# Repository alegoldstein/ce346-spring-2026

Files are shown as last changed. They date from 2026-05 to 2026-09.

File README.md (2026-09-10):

# Electronic Game Table
# ce346-spring-2026

Firmware and PCB design for COMP_ENG 346: Microcontroller System Design.

For this project my group created an electronic table that added animations and score tracking to the common college games of beer pong and beer die.

To do so, we CNC'd a wooden table with channels to pour epoxy and placed ~800 WS2812B LEDs. Each half of the table had its own PCB (which are identical) which was responsible for monitoring the game state and controlling the LEDs accordingly using the FastLED library. Lastly, the power for this project was a large challenge because of the high current draw that WS2812B LEDs are capable of. To avoid overheating, we never had LEDs on at full brightness and avoided the color white as much as possible. The power source we used was capable of supplying 60A at 5V so monitoring shorts was also a high priority. We used bus bars that were suited for handling 60A and separated power and ground with large margins to avoid any accidental shorts. To ensure a uniform brightness level we added power injections to the LED strips with carefuly planned channels cut around in the available space left around the epoxy. 

<table align="center">
  <tr>
    <td align="center">
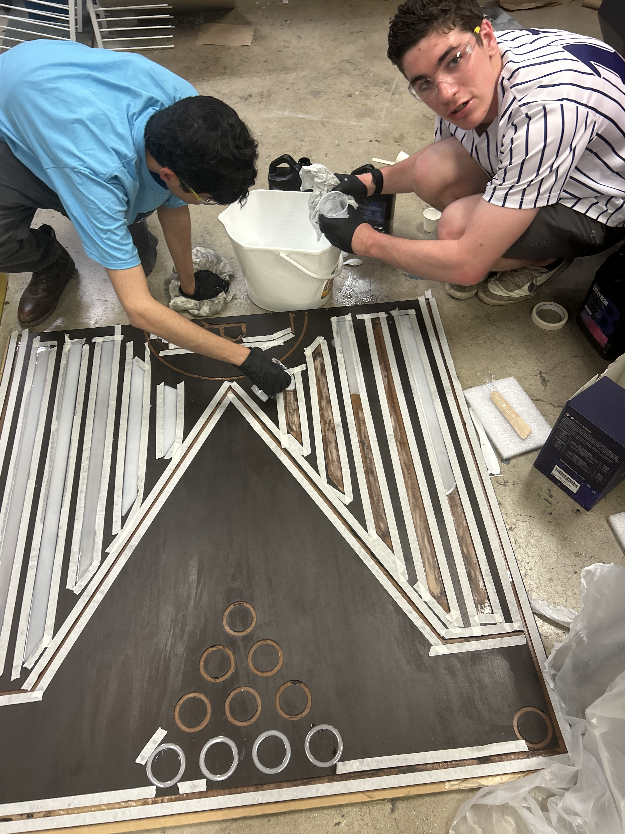
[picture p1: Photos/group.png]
      <br>
      <em>The three of us pouring epoxy</em>
    </td>
    <td align="center">
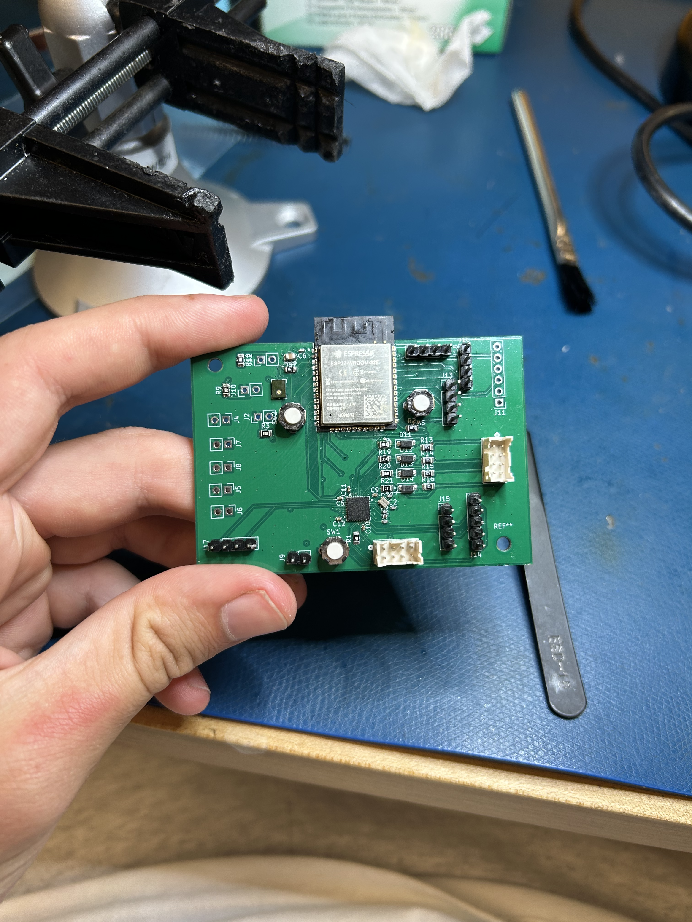
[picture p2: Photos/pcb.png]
      <br>
      <em>Fully assembled PCB</em>
    </td>
  </tr>
</table>

<table align="center">
  <tr>
    <td align="center">
      <br>
      <em>Inside of table while routing power and LEDs</em>
    </td>
    <td align="center">
      <br>
      <em>Setting up for demo, LED ring on where cup is placed</em>
    </td>
  </tr>
</table>

I hand wrote the game state code in C for an NRF52833 chip (found in NRF->software->apps->rave_rack) that used a 16 bit variable where bits 0-11 each represented 1 of the 12 cups on a half of a board (10 for pong and 2 for die). The NRF chip was also responsible for cycling through an 16 channel analog multiplexer used to check the values of IR sensors placed beneath each cup to determine whether they had been picked up or not. This information can be used to update the game state and infer the score (more cups missing means other teams score goes up). The NRF chip then communicates the game state to an ESP32 which was responsible for controlling the LEDs.

I also wrote C++ code for the ESP32 to animate the LEDs in response to game state changes. For example, during initialization the LEDs would snake around the border to indicate it was turned on and ready. If a cup was lifted (meaning someone scored) a celebration animation would occur. The FastLED library made this simpler since all that was needed was a buffer with each color and brightness we wanted each LED.

The reasoning for having 2 separate MCUs is due to the class being based on the NRF52833 chip, but our group running out of pins since we had a larger scope than expected for a 4 week project. 

https://github.com/user-attachments/assets/d65dbca0-1492-469c-94e2-22f77370f840

One half of the table featuring LED animations with epoxy cover on top

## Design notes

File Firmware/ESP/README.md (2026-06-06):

ESP controls LEDs under the table and the scoreboard

nrf52833 sends the game state over spi and the ESP responds accordingly

the ESP has the game mode switch button which it will communicate if pressed to the nrf

the two halfs of the table communicate via the ESP of each board being connected with UART

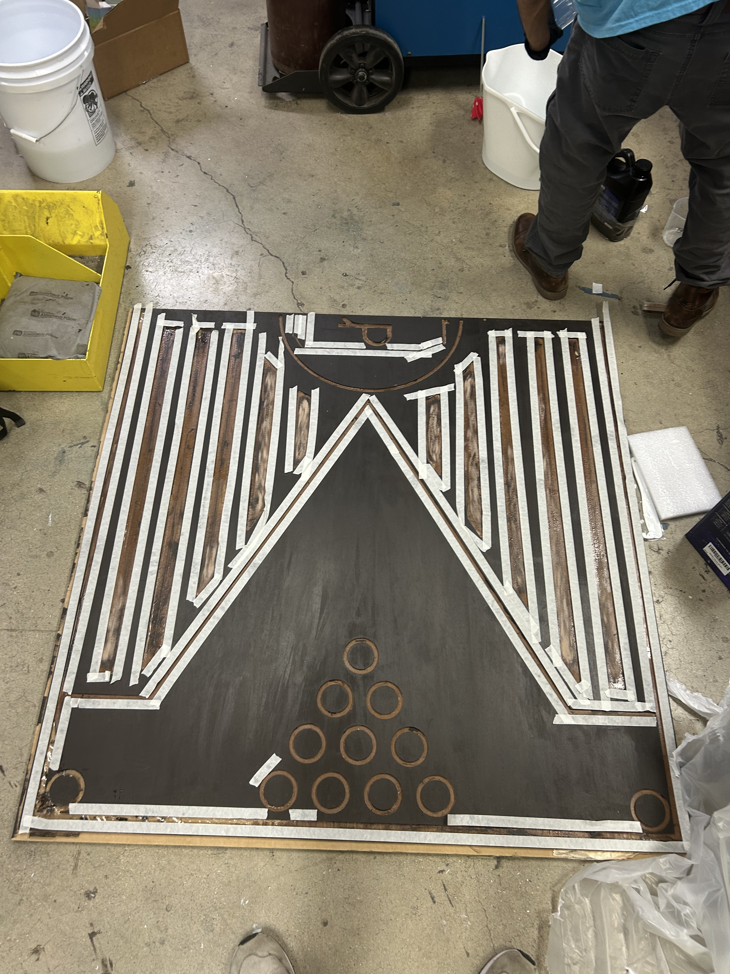
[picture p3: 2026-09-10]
Photos/Epoxy.png

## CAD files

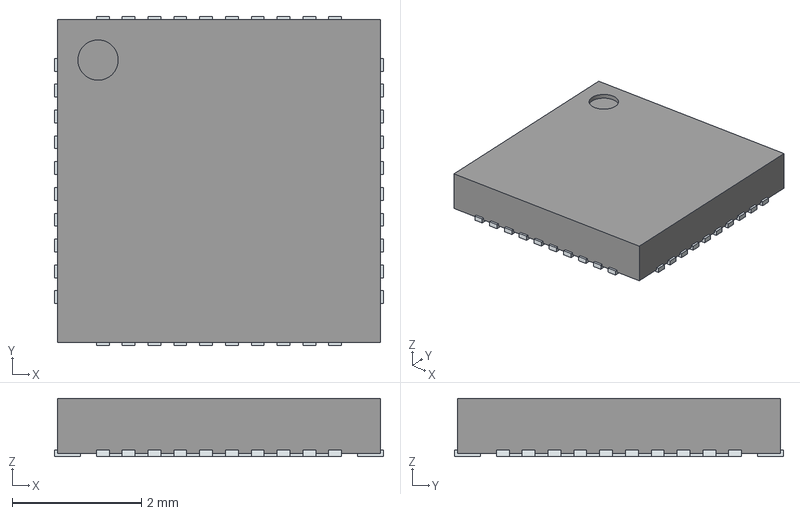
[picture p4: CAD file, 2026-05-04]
PCB/LIB_nRF52833-QDAA-R/nRF52833-QDAA-R/3D/nRF52833-QDAA-R.stp
5.10 x 5.10 x 0.9 mm
ThermalPin
PinsArrayLR
PinsArrayTB

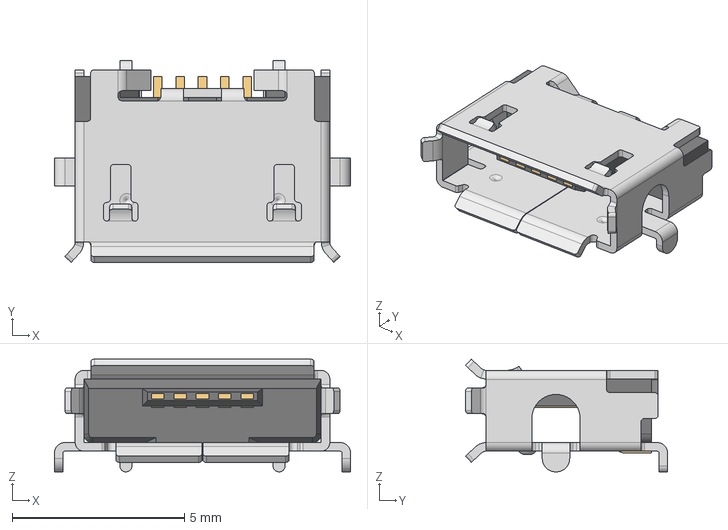
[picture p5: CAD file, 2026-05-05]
PCB/micro usb/629105150921.step
8.60 x 5.87 x 3.27 mm
629105150921_Pin x 5

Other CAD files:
PCB/LIB_nRF52833-QDAA-R/nRF52833-QDAA-R/Allegro/qfn40p500x500x90-41n.psm
PCB/LIB_nRF52833-QDAA-R/nRF52833-QDAA-R/DEHDL/nrf52833_qdaa_r/chips/chips.prt

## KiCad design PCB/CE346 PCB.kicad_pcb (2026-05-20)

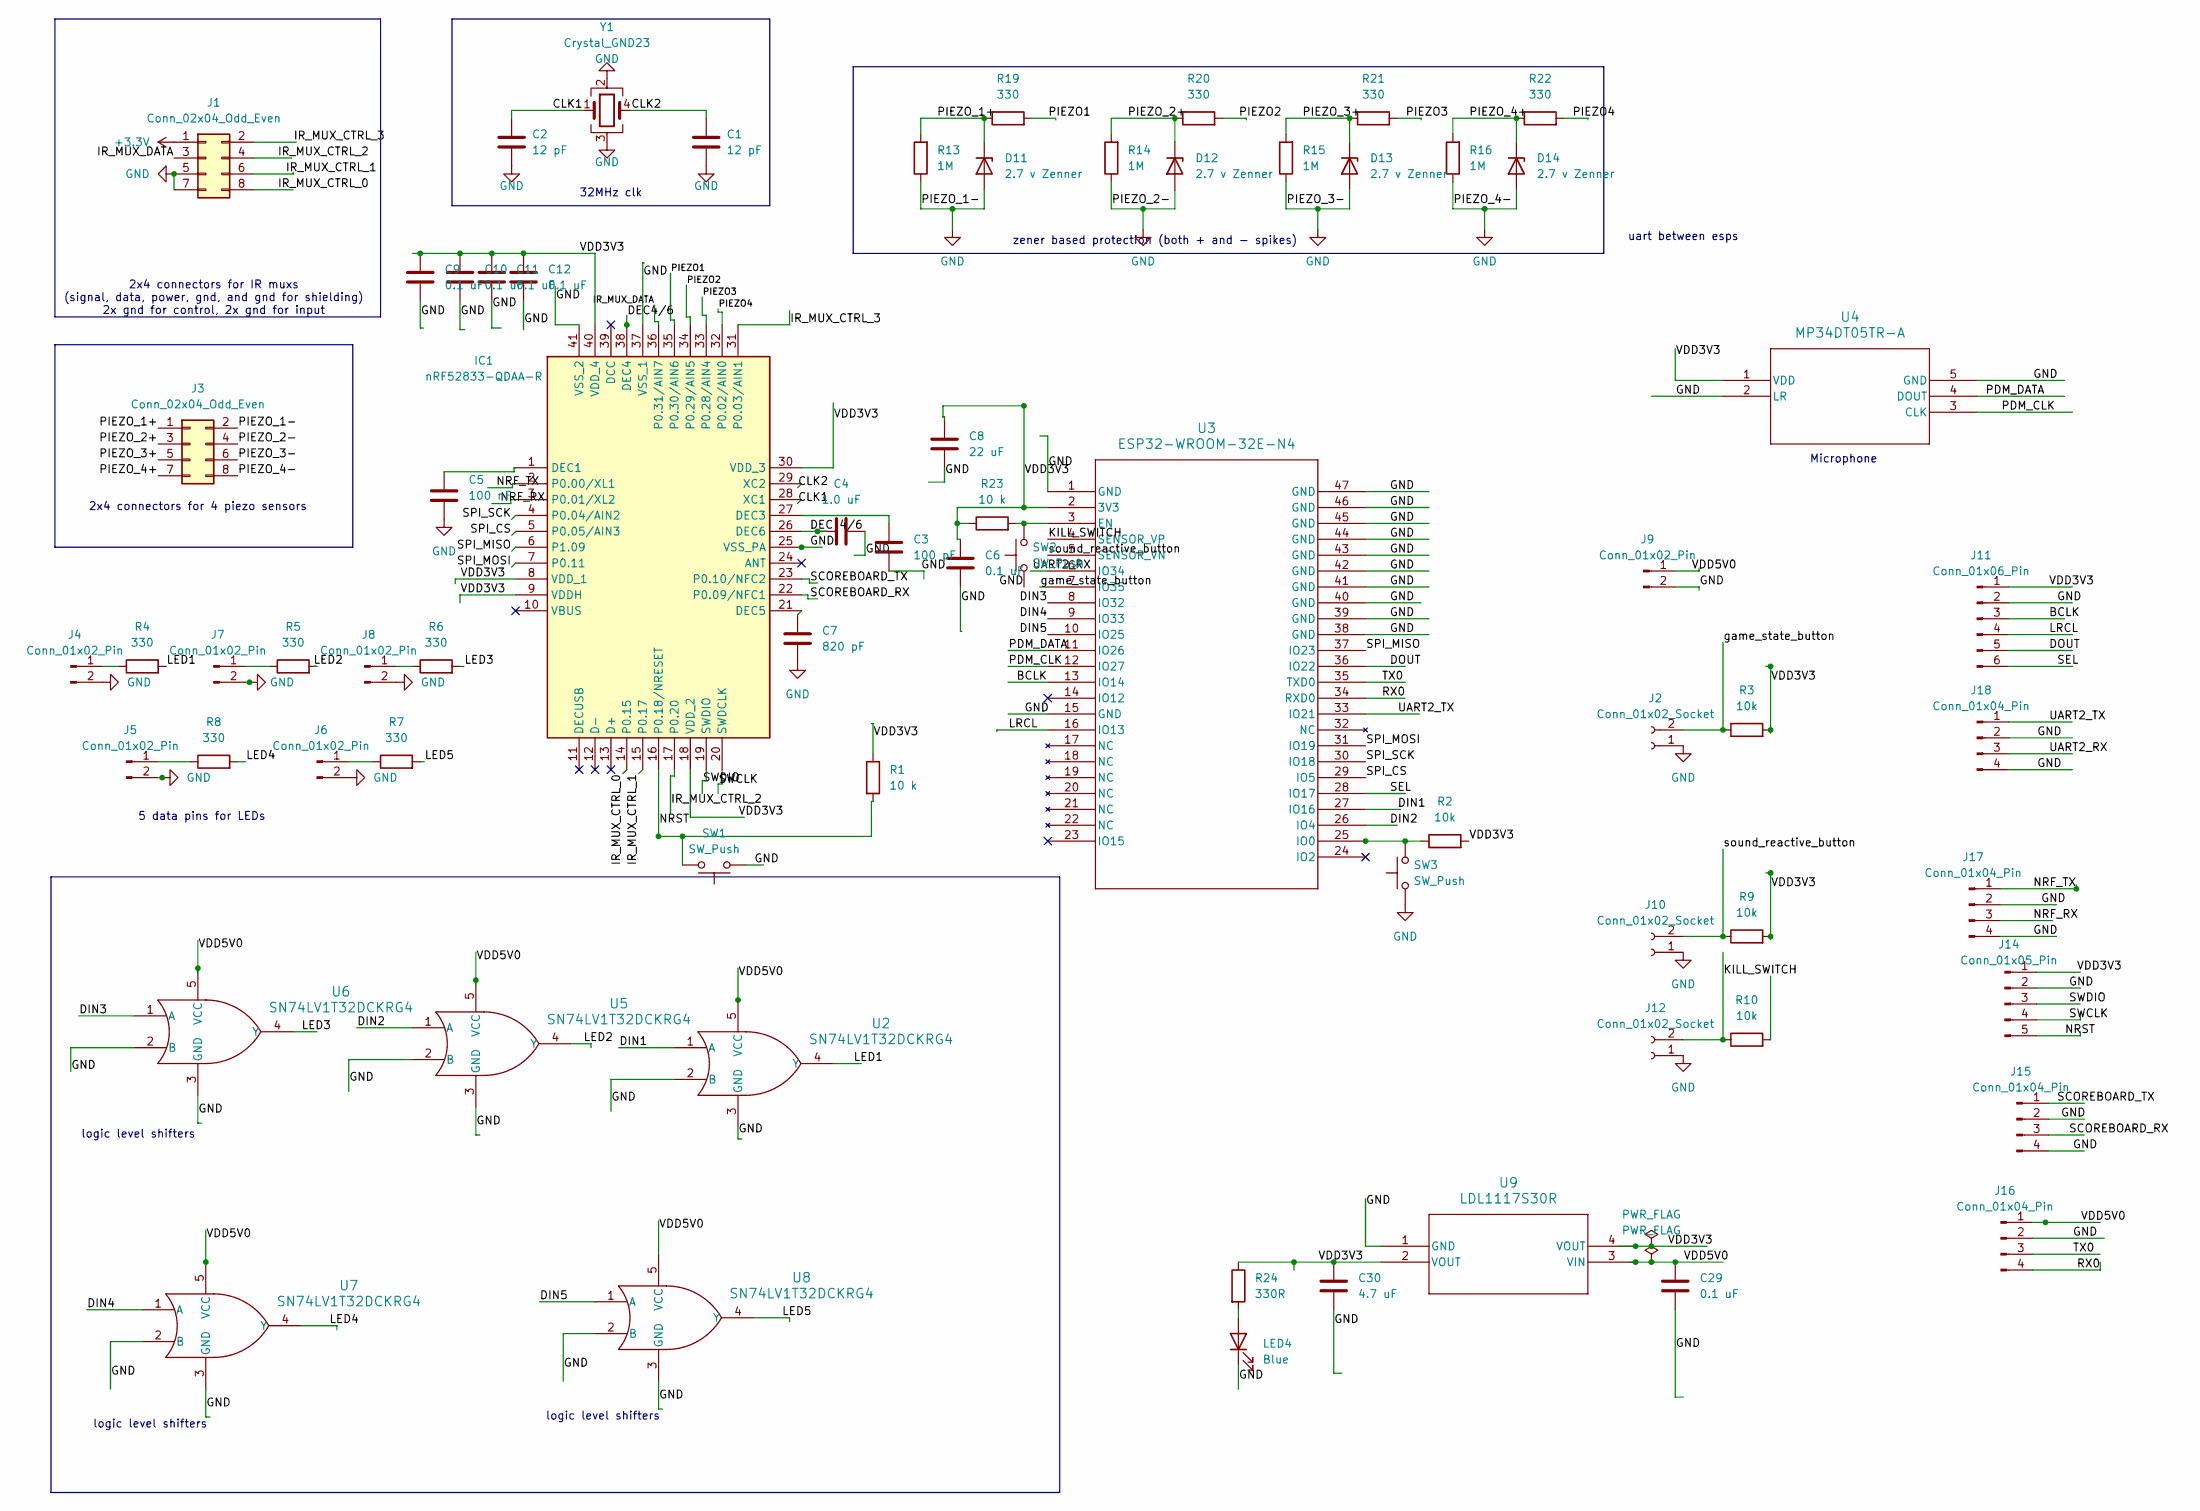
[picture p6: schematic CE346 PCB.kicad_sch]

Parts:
C1, C2: 12 pF; C_0402_1005Metric
C3: 100 pF; C_0402_1005Metric
C4: 1.0 uF; C_0402_1005Metric
C5: 100 nF; C_0402_1005Metric
C6, C9, C10, C11, C12, C29: 0.1 uF; C_0402_1005Metric
C7: 820 pF; C_0402_1005Metric
C8: 22 uF; C_0805_2012Metric
C30: 4.7 uF; C_0805_2012Metric
D11, D12, D13, D14: 2.7 v Zenner; D_SOD-123
IC1: nRF52833-QDAA-R; QFN40_5X5_DQ_NOR-L; Mouser Part Number 949-NRF52833-QDAA-R
J1, J3: Conn_02x04_Odd_Even; 2x4 jst
J2, J10, J12: Conn_01x02_Socket; PinHeader_1x02_P2.54mm_Vertical
J4, J5, J6, J7, J8, J9: Conn_01x02_Pin; PinHeader_1x02_P2.54mm_Vertical
J11: Conn_01x06_Pin; PinHeader_1x06_P2.54mm_Vertical
J14: Conn_01x05_Pin; PinHeader_1x05_P2.54mm_Vertical
J15, J16, J17, J18: Conn_01x04_Pin; PinHeader_1x04_P2.54mm_Vertical
LED4: Blue; LED_0603_1608Metric
R1, R23: 10 k; R_0805_2012Metric
R2, R3, R9, R10: 10k; R_0805_2012Metric
R4, R5, R6, R7, R8, R19, R20, R21, R22: 330; R_0805_2012Metric
R13, R14, R15, R16: 1M; R_0805_2012Metric
R24: 330R; C_0402_1005Metric
SW1, SW2, SW3: SW_Push; pushbutton
U2, U5, U6, U7, U8: SN74LV1T32DCKRG4; DBV0005A_N
U3: ESP32-WROOM-32E-N4; ESP32­WROOM­32E_EXP
U4: MP34DT05TR-A; MP34DT05TR-A_STM
U9: LDL1117S30R; SOT223_STM
Y1: Crystal_GND23; 32MHz Crystal

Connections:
+3.3V: J1.1
/BCLK: J11.3, U3.13 (IO14)
/CLK1: C2.1, IC1.28 (XC1), Y1.1
/CLK2: C1.1, IC1.29 (XC2), Y1.4
/DIN1: U2.1 (A), U3.27 (IO16)
/DIN2: U3.26 (IO4), U5.1 (A)
/DIN3: U3.8 (IO32), U6.1 (A)
/DIN4: U3.9 (IO33), U7.1 (A)
/DIN5: U3.10 (IO25), U8.1 (A)
/DOUT: J11.5, U3.36 (IO22)
/IR_MUX_CTRL_0: IC1.14 (P0.15), J1.8
/IR_MUX_CTRL_1: IC1.15 (P0.17), J1.6
/IR_MUX_CTRL_2: IC1.17 (P0.20), J1.4
/IR_MUX_CTRL_3: IC1.31 (P0.03/AIN1), J1.2
/IR_MUX_DATA: IC1.36 (P0.31/AIN7), J1.3
/KILL_SWITCH: J12.2, R10.1, U3.4 (SENSOR_VP)
/LED1: R4.2, U2.4 (Y)
/LED2: R5.2, U5.4 (Y)
/LED3: R6.2, U6.4 (Y)
/LED4: R8.2, U7.4 (Y)
/LED5: R7.2, U8.4 (Y)
/LRCL: J11.4, U3.16 (IO13)
/NRF_RX: IC1.3 (P0.01/XL2), J17.3
/NRF_TX: IC1.2 (P0.00/XL1), J17.1
/NRST: IC1.16 (P0.18/NRESET), J14.5, R1.2, SW1.2
/PDM_CLK: U3.12 (IO27), U4.3 (CLK)
/PDM_DATA: U3.11 (IO26), U4.4 (DOUT)
/PIEZO1: IC1.35 (P0.30/AIN6), R19.2
/PIEZO2: IC1.34 (P0.29/AIN5), R20.2
/PIEZO3: IC1.33 (P0.28/AIN4), R21.2
/PIEZO4: IC1.32 (P0.02/AIN0), R22.2
/PIEZO_1+: D11.1 (K), J3.1, R13.2, R19.1
/PIEZO_2+: D12.1 (K), J3.3, R14.2, R20.1
/PIEZO_3+: D13.1 (K), J3.5, R15.2, R21.1
/PIEZO_4+: D14.1 (K), J3.7, R16.2, R22.1
/RX0: J16.4, U3.34 (RXD0)
/SCOREBOARD_RX: IC1.22 (P0.09/NFC1), J15.3
/SCOREBOARD_TX: IC1.23 (P0.10/NFC2), J15.1
/SEL: J11.6, U3.28 (IO17)
/SPI_CS: IC1.5 (P0.05/AIN3), U3.29 (IO5)
/SPI_MISO: IC1.6 (P1.09), U3.37 (IO23)
/SPI_MOSI: IC1.7 (P0.11), U3.31 (IO19)
/SPI_SCK: IC1.4 (P0.04/AIN2), U3.30 (IO18)
/SWCLK: IC1.20 (SWDCLK), J14.4
/SWDIO: IC1.19 (SWDIO), J14.3
/TX0: J16.3, U3.35 (TXD0)
/UART2_RX: J18.3, U3.6 (IO34)
/UART2_TX: J18.1, U3.33 (IO21)
/VDD3V3: C6.1, C8.1, C9.1, C10.1, C11.1, C12.1, C30.2, IC1.8 (VDD_1), IC1.9 (VDDH), IC1.18 (VDD_2), IC1.30 (VDD_3), IC1.40 (VDD_4), J11.1, J14.1, R1.1, R2.2, R3.2, R9.2, R23.1, R24.1, U3.2 (3V3), U4.1 (VDD), U9.2 (VOUT), U9.4 (VOUT)
/VDD5V0: C29.2, J9.1, J16.1, U2.5 (VCC), U5.5 (VCC), U6.5 (VCC), U7.5 (VCC), U8.5 (VCC), U9.3 (VIN)
/game_state_button: J2.2, R3.1, U3.7 (IO35)
/sound_reactive_button: J10.2, R9.1, U3.5 (SENSOR_VN)
GND: C1.2, C2.2, C3.2, C4.2, C5.2, C6.2, C7.2, C8.2, C9.2, C10.2, C11.2, C12.2, C29.1, C30.1, D11.2 (A), D12.2 (A), D13.2 (A), D14.2 (A), IC1.25 (VSS_PA), IC1.37 (VSS_1), IC1.41 (VSS_2), J1.5, J1.7, J2.1, J3.2, J3.4, J3.6, J3.8, J4.2, J5.2, J6.2, J7.2, J8.2, J9.2, J10.1, J11.2, J12.1, J14.2, J15.2, J15.4, J16.2, J17.2, J17.4, J18.2, J18.4, LED4.1 (K), R13.1, R14.1, R15.1, R16.1, SW1.1, SW2.1, SW3.1, U2.2 (B), U2.3 (GND), U3.1 (GND), U3.15 (GND), U3.38 (GND), U3.39 (GND), U3.40 (GND), U3.41 (GND), U3.42 (GND), U3.43 (GND), U3.44 (GND), U3.45 (GND), U3.46 (GND), U3.47 (GND), U4.2 (LR), U4.5 (GND), U5.2 (B), U5.3 (GND), U6.2 (B), U6.3 (GND), U7.2 (B), U7.3 (GND), U8.2 (B), U8.3 (GND), U9.1 (GND), Y1.2, Y1.3
unnamed: C5.1, IC1.1 (DEC1)
unnamed: C3.1, IC1.27 (DEC3)
unnamed: C7.1, IC1.21 (DEC5)
unnamed: J4.1, R4.1
unnamed: J5.1, R8.1
unnamed: J6.1, R7.1
unnamed: J7.1, R5.1
unnamed: J8.1, R6.1
unnamed: LED4.2 (A), R24.2
unnamed: R23.2, SW2.2, U3.3 (EN)
unnamed: R2.1, SW3.2, U3.25 (IO0)

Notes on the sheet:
Microphone
5 data pins for LEDs
32MHz clk
logic level shifters
zener based protection (both + and - spikes)
uart between esps
2x4 connectors for 4 piezo sensors
2x4 connectors for IR muxs (signal, data, power, gnd, and gnd for shielding) 2x gnd for control, 2x gnd for input

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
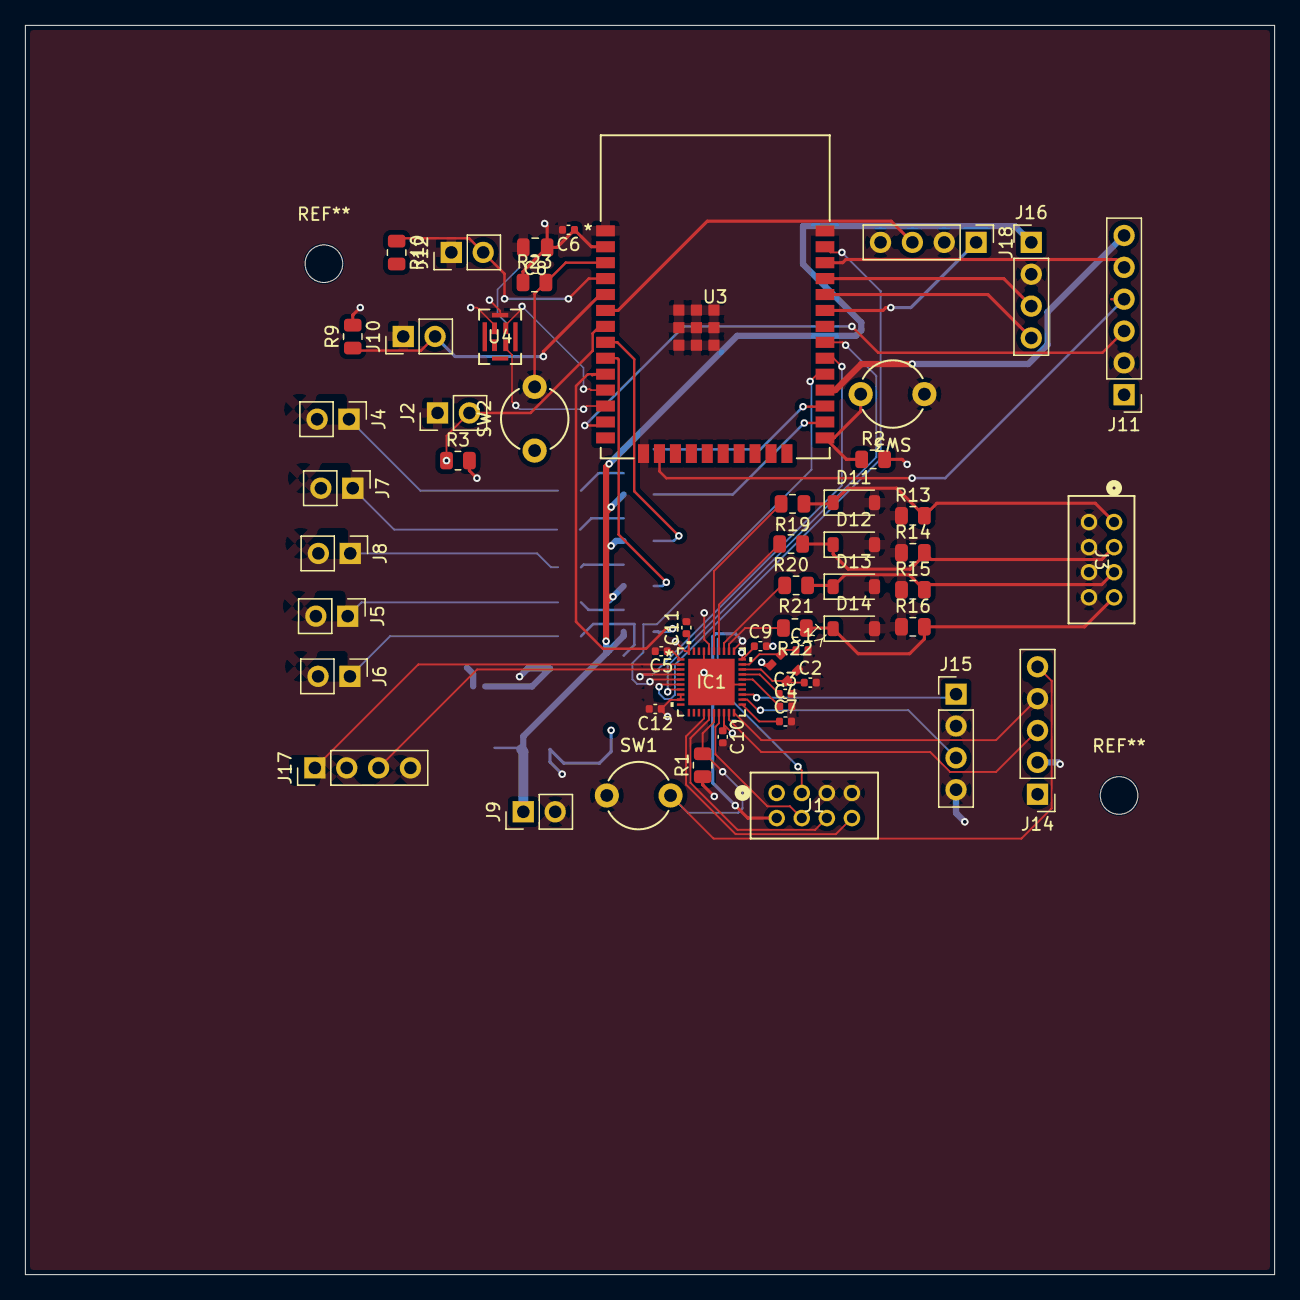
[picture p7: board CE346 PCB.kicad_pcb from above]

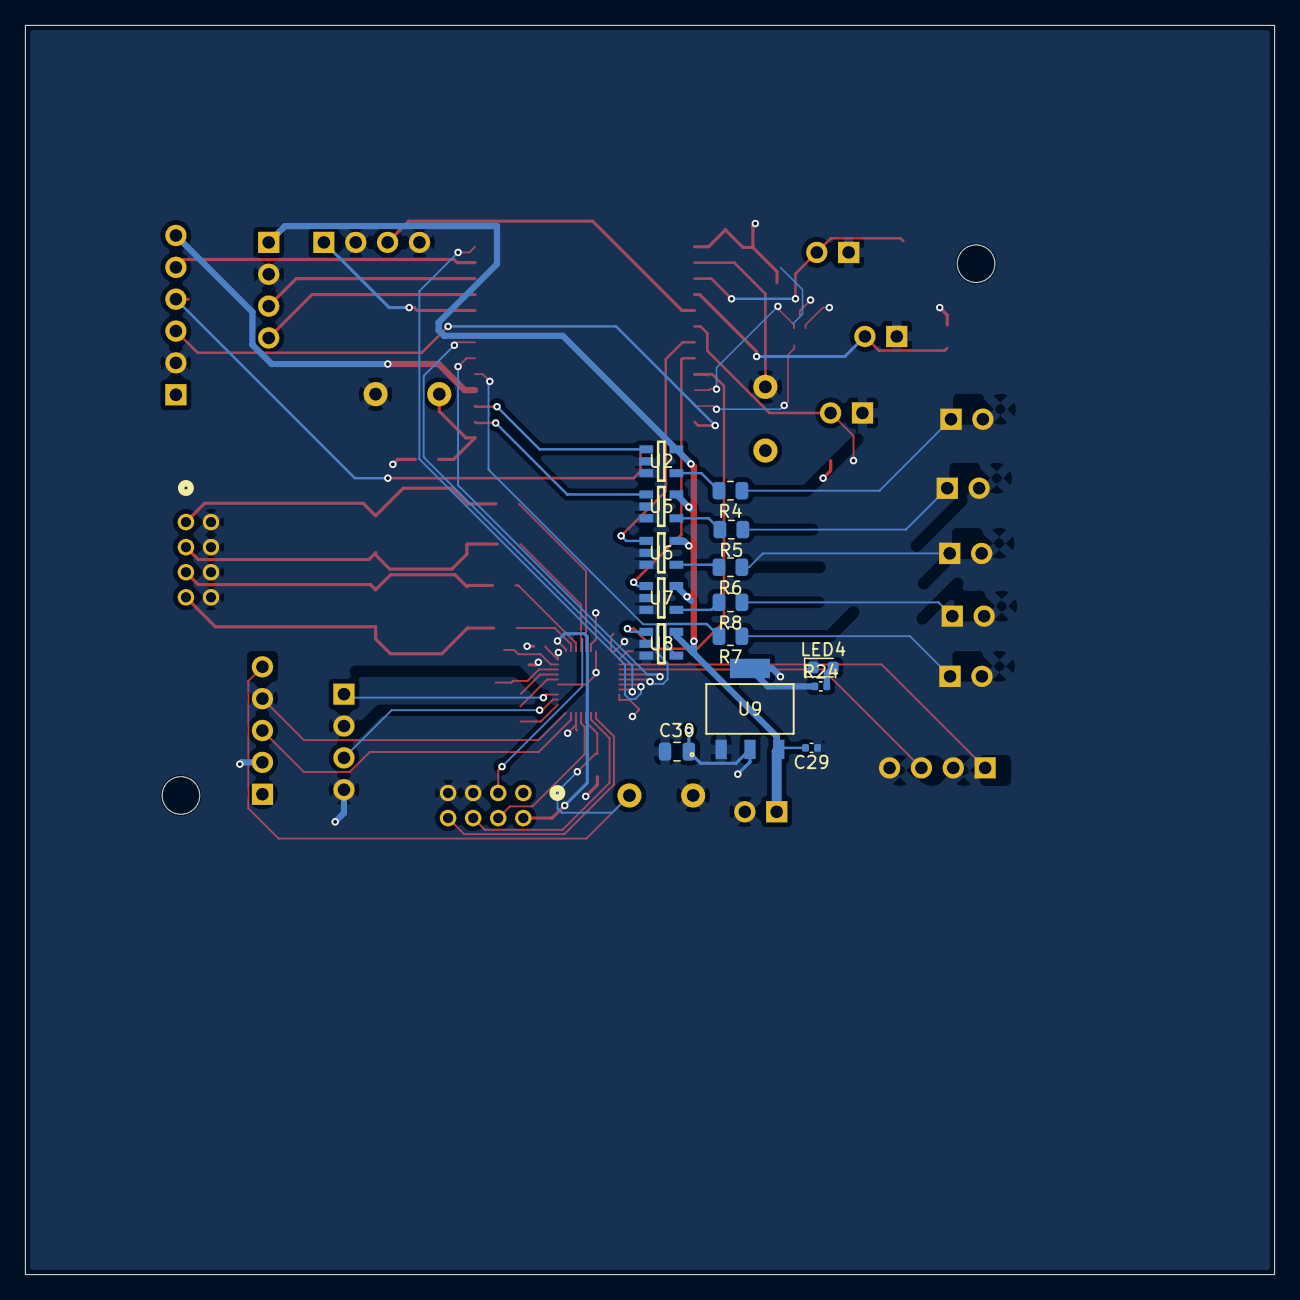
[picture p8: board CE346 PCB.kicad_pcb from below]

Board: 4 copper layers, 99.6 x 99.6 mm, 69 parts (15 on the bottom side), 64 nets.

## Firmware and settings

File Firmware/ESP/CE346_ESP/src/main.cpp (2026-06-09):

#include <Arduino.h>
#include <FastLED.h>
#include "led.h"

// --- MUX pins ---
#define MUX_A   25
#define MUX_B   26
#define MUX_C   27
#define MUX_OUT 36

#define IR_THRESHOLD 600
#define LED_PIN      23
#define NUM_LEDS     140

extern CRGB test[];

const uint8_t cup_lengths[10] = {14,14,14,14,14,14,14,14,14,13};
uint16_t cup_start[10];
bool cup_on[10] = {false};

// ir channel -> cup index (-1 = unused)
// IR 0-5 -> cups 1-6 (index 0-5)
// IR 6   -> cup 8 (index 7)
// IR 7   -> cup 9 (index 8)
// cups 7 and 10 (index 6 and 9) always off
const int8_t ir_to_cup[8] = {0, 1, 4, 3, 2, 5, 7, 8};

// --- MUX helpers ---
void muxSelect(uint8_t channel){
    digitalWrite(MUX_A,  channel & 0x01);
    digitalWrite(MUX_B, (channel >> 1) & 0x01);
    digitalWrite(MUX_C, (channel >> 2) & 0x01);
    delayMicroseconds(5);
}

int readMuxChannel(uint8_t channel){
    muxSelect(channel);
    delayMicroseconds(20);
    int sum = 0;
    for (int i = 0; i < 8; i++){
        sum += analogRead(MUX_OUT);
        delayMicroseconds(50);
    }
    return sum / 8;
}

void setCupColor(uint8_t cup, CRGB color){
    for (uint16_t i = cup_start[cup]; i < cup_start[cup] + cup_lengths[cup]; i++){
        test[i] = color;
    }
}

void setup(){
    Serial.begin(115200);

    pinMode(MUX_A, OUTPUT);
    pinMode(MUX_B, OUTPUT);
    pinMode(MUX_C, OUTPUT);
    pinMode(MUX_OUT, INPUT);
    analogReadResolution(12);
    analogSetPinAttenuation(MUX_OUT, ADC_11db);

    FastLED.addLeds<WS2812B, LED_PIN>(test, NUM_LEDS).setCorrection(TypicalLEDStrip);
    FastLED.setBrightness(255);
    fill_solid(test, NUM_LEDS, CRGB::Black);
    FastLED.show();

    cup_start[0] = 0;
    for (uint8_t i = 1; i < 10; i++){
        cup_start[i] = cup_start[i-1] + cup_lengths[i-1];
    }

    // ensure uncontrolled cups 7 and 10 (index 6, 9) are off
    setCupColor(6, CRGB::Black);
    setCupColor(9, CRGB::Black);
    FastLED.show();

    Serial.println("Ready");
    //led_test();
}

void loop(){
    // Serial.println("---- MUX Scan ----");
    // for (uint8_t ch = 0; ch < 8; ch++){
    //     int value = readMuxChannel(ch);
    //     Serial.print("CH"); Serial.print(ch); Serial.print(": "); Serial.println(value);

    //     int8_t cup = ir_to_cup[ch];

    //     if (value < IR_THRESHOLD){
    //         cup_on[cup] = true;
    //     } else {
    //         cup_on[cup] = false;
    //     }

    //     setCupColor(cup, cup_on[cup] ? CRGB::Blue : CRGB::Black);
    // }
    // Serial.println();

    // FastLED.show();
    // delay(100);
    //led_test();
    led_test();
    
}

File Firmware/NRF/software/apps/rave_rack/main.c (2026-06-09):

#include <stdbool.h>
#include <stdint.h>
#include <stdio.h>

#include "game_logic.h"
#include "nrf_delay.h"
#include "microbit_v2.h"

game_state_t game;
nrfx_spim_t spim_inst;
uint8_t adc_limit = 0x3F;
uint8_t esp_data_buf = {0};
uint8_t corners = 0; //2 left bits = bottom left, 2 left middle bits = bottom right, 2 right middle bits = top left, 2 right bits = top right
bool send_audio = false;

int main(void) {
    //set game defaults
    init_game(&game, &spim_inst);

    //main loop
    while(1) {
        if (game.PONG) {
            uint8_t count = 0;
            for (uint8_t i = 0; i < 8; i++){
                //control mux to gather IR sensor data
                IR_MUX_CONTROL0 = i & 0b0001;
                IR_MUX_CONTROL1 = i & 0b0010;
                IR_MUX_CONTROL2 = i & 0b0100;
                IR_MUX_CONTROL3 = i & 0b1000;
                
                if (i < 10) { //only for cups on diamond
                    //threshold to determine if cup is off table
                    if (IR_MUX_DATA < IR_THRESH) {
                        count++;
                        game.TEAM_1_CUPS &= !(1 << i); //update cup states
                    }
                }
            }
            //set score
            game.TEAM_1_SCORE = count;

            //communicate to ESP
                // Perform a SPI transmission (COPI)
                uint8_t data[4] = {0x00, 0x0F, 0xF0, 0xFF};
                nrfx_spim_xfer_desc_t data_xfer = NRFX_SPIM_XFER_TX(&data, 4);
                nrfx_spim_xfer(&SPIM_INST, &data_xfer, 0);
        }
        if (send_audio){
            //prepare data buffer with audio

        }

    }

}

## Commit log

2026-05-04 schematic work
    [CE346 PCB.kicad_pcb, CE346 PCB.kicad_sch, EDI2CAP.CFG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]
2026-05-05 better schematic
    [629105150921.step]
2026-05-05 small changes
    [CE346 PCB.kicad_sch]
2026-05-19 Finally added all of these files so I won't lose them again
    [CE346 PCB.kicad_sch]
2026-05-19 updating the footprint and symbols libraries
2026-05-19 updating the footprint library again
2026-05-19 pushing the changes
    [CE346 PCB.kicad_pcb, CE346 PCB.kicad_sch]
2026-05-20 pushing the changes to the routed PCB
    [CE346 PCB.kicad_pcb, CE346 PCB.kicad_sch]
2026-06-04 game flow work
2026-06-05 Added PCB testing code and copied nrf52x-base directory to enable flashing
2026-06-05 Reorganized directory hierarchy
    [629105150921.step, CE346 PCB.kicad_pcb, CE346 PCB.kicad_sch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]
2026-06-07 adc interrupts
2026-06-08 led test
2026-06-09 esp code for ir sensors
2026-09-10 Update README with LED animations description
    Added a description for the LED animations table.
